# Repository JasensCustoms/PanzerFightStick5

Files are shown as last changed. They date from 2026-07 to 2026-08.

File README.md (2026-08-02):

<p align="center">
  Jasen's Customs Logo
</p>

# Panzer Fight Stick 5

Design files for the **Panzer Fight Stick 5**, provided for **personal, non-commercial use only.**

> **Please read the License section below before using anything in this repository.**

## What's in This Repo

This repository contains STEP files (`.step` / `.stp`) for the Panzer Fight Stick 5 case, plus supporting hardware files.

- `panzer-fightstick-5-v2-*.STEP` — top panel variants (AB, AEGS2, NOIR, SP1, SP2, Vewlix, and blank)
- `panzer-fightstick-5-bottom.STEP` — bottom panel
- `Full-Panzer-SP1MX_PCB_ProductionFiles.zip` / `Full-Panzer_SP2MX_ProductionFiles.zip` — PCB production files
- `HardwareSpecs.md` — hardware specifications
- `NeutrikFix/` and `Panzer5-NeutrikFix-3.3MF` — Neutrik mount fix parts
- `USBPowerAdapter/` — USB power adapter files
- `plexitemplates/` — plexi templates

## Tapping & Threading

The following thread specifications are provided as general guidance. Always verify against your specific hardware before tapping.

- **MX / HE PCBs:** generally use **#6-32** threading.
- **Brook PCB mounting points:** generally use **#4-40** threading.
- **Lever mount points:** generally use **#6-32** threading.
- **Top and bottom panels:** use **M4x0.7** threading.

## Community & Discussion

Questions, ideas, or just want to talk builds? Join the Jasen's Customs Discord: [discord.gg/UJmNMunTqa](https://discord.gg/UJmNMunTqa)

## License — Personal, Non-Commercial Use Only

Copyright © 2026 Jasen Hicks ([www.JasensCustoms.com](https://www.JasensCustoms.com)). All rights reserved.

These designs are provided **solely for personal, private, non-commercial use.** You may build units for yourself, modify the designs for your own projects, and share the unmodified files (with attribution and the license intact). You may **not** sell parts, kits, units, or derivatives, manufacture for profit, or use these files commercially in any way.

Full terms — including the **No Warranty** and **No Support** notices — are in [LICENSE.md](LICENSE.md). By downloading, copying, or using any file in this repository, you agree to them.

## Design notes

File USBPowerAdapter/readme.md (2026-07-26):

Added 3d print files for the USB Power Adapater. Requires M3 threaded inserts from RUTHEX.

Connect the Red Wire from either of the two pins on the USB Power Adapter and here on the HE PCB (TMS)



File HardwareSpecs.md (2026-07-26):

Plexi and Top Panel: 
6x M4x12mm Button Head Screw

Fighting Board:
4x #4-40x.75in
4x Plastic Spacers (ID3.2, OD.7, 11mm Long)

Front USB Mount: 
2x #4-40 Flat Head Screw, 1/2" Long (Counter Sink)

Bottom Panel:
4x M4x12mm Button Head Screw
2x M4x12mm Flat Head Screw (Counter Sink)

Lever Mount For Lever Based Panels:
4x #6-32 Truss Head Screw, 1/2" long (JLF)
4x #6-32 Pan Head Screw, 3/4" Long (usually) (KR Lever)
4x #6 Flat Washers
4x #6 Lock Washers

MX Panels PCB Screws:

12x #6-32 Truss Head Screws (1/2" Long)

Feet:
4x Feet from Parts Express
https://www.parts-express.com/4-Pack-Rubber-Cabinet-Feet-0.88-Dia.-x-0.31-H-260-7508?quantity=1

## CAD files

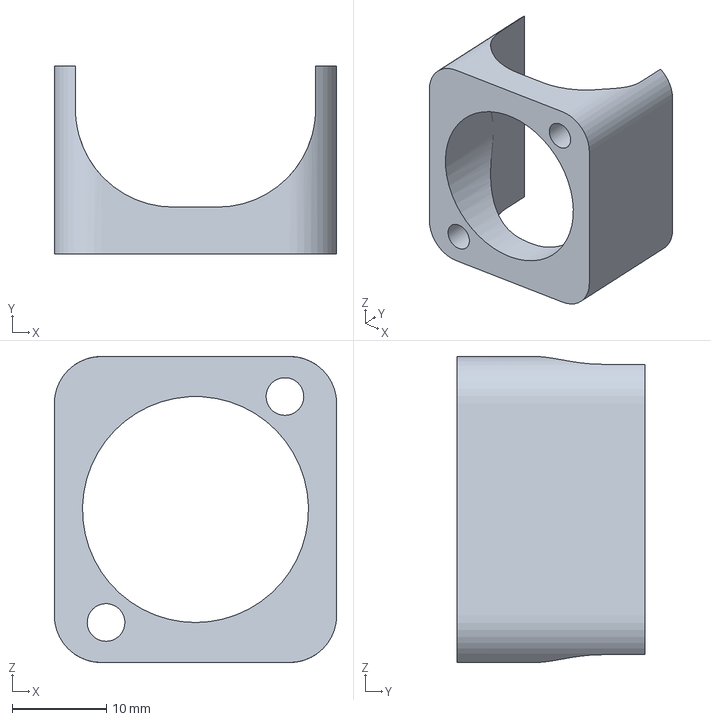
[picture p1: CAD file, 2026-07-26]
NeutrikFix/Panzer5-NeutrikFix-3.3MF
30.0 x 20.0 x 32.5 mm

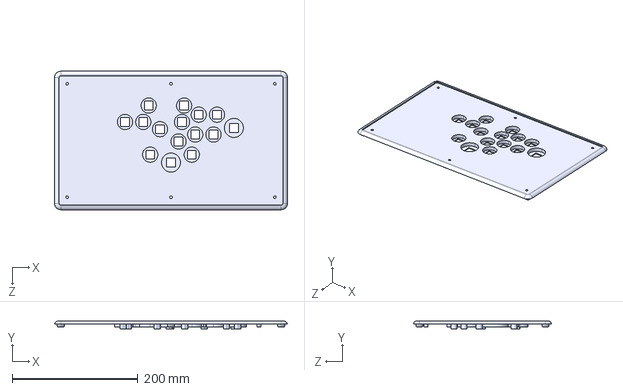
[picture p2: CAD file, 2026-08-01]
panzer-fightstick-5-v2-AEGS2MX.STEP
370.0 x 13.0 x 220.0 mm

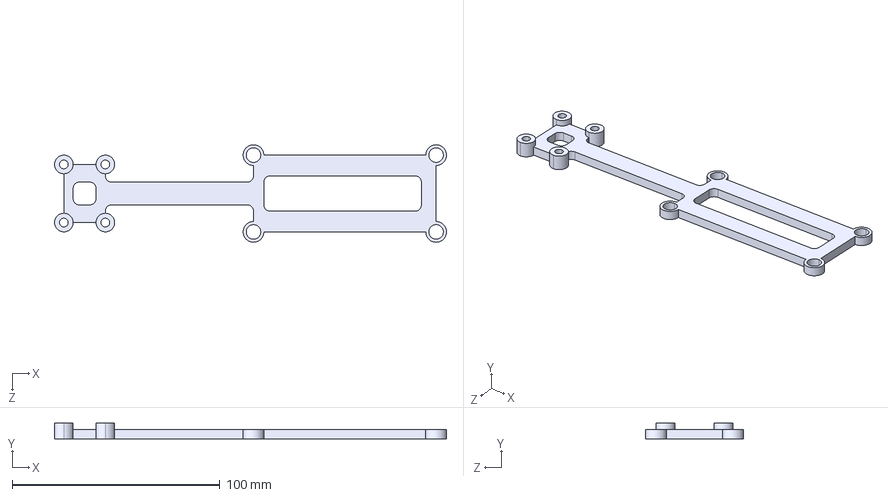
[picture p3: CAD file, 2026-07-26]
USBPowerAdapter/PowerAdapterPCBHolder.STEP
188.9 x 7.50 x 47.0 mm

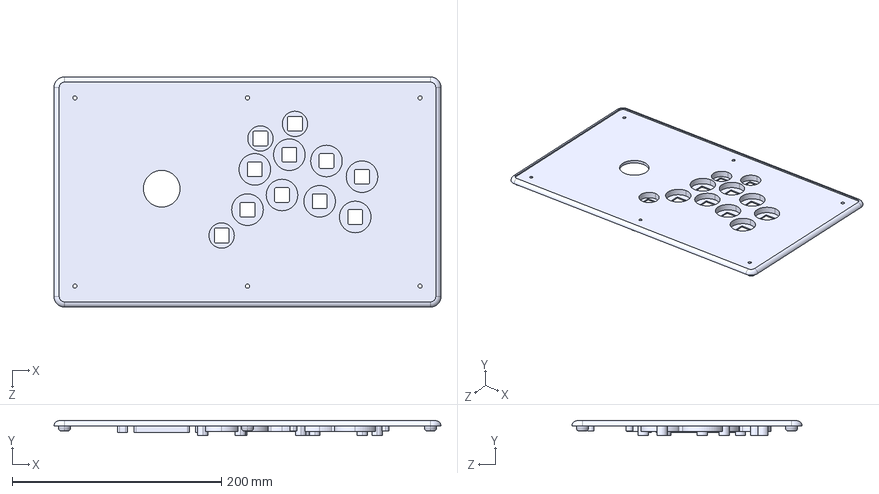
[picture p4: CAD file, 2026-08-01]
panzer-fightstick-5-v2-SP1MX.STEP
370.0 x 14.0 x 220.0 mm

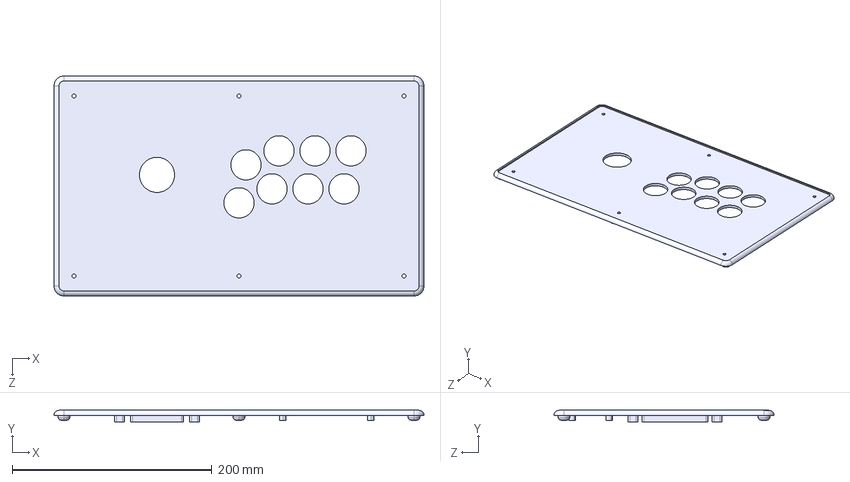
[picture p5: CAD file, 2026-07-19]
panzer-fightstick-5-v2-VEWLIX-StandardButtons.STEP
370.0 x 11.5 x 220.0 mm

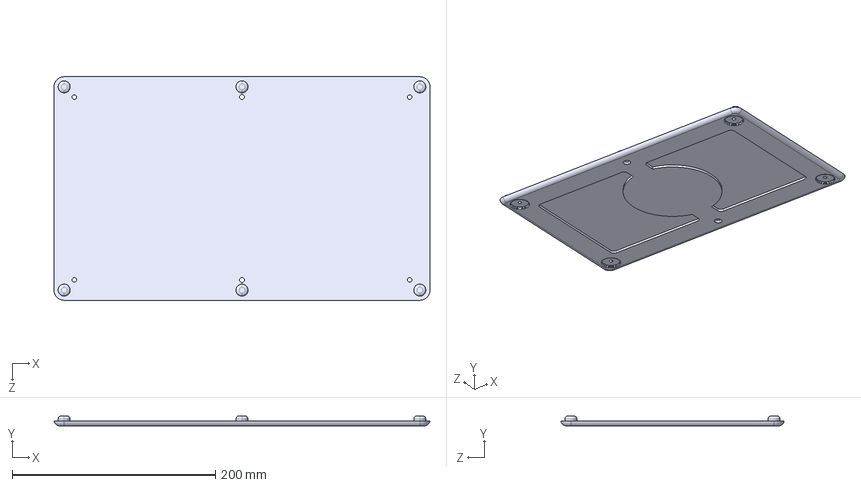
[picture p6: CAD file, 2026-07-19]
panzer-fightstick-5-bottom.STEP
370.0 x 10.0 x 220.0 mm

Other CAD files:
panzer-fightstick-5-v2-ABMX.STEP
panzer-fightstick-5-v2-toppanel-blank.STEP

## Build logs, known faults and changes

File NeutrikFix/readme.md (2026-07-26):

Some blemished Panzer 5 cases require this neturik fix. It lets you pass through long (1.75") #4-40 screws through the oversized holes and have a flat surface to secure the nuts and washers.

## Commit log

2026-07-26 Add 3D print files for USB Power Adapter
    Includes necessary components for assembly.
2026-07-26 Update readme with 3D print files and connection details
    Added instructions for connecting the USB Power Adapter and included an image.
